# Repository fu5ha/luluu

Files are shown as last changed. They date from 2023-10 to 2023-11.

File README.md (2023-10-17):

# LuLuu!

A cute and smart arm-warmer sleeve with a 1.3" full color TFT display built into the back of the
hand ^_^

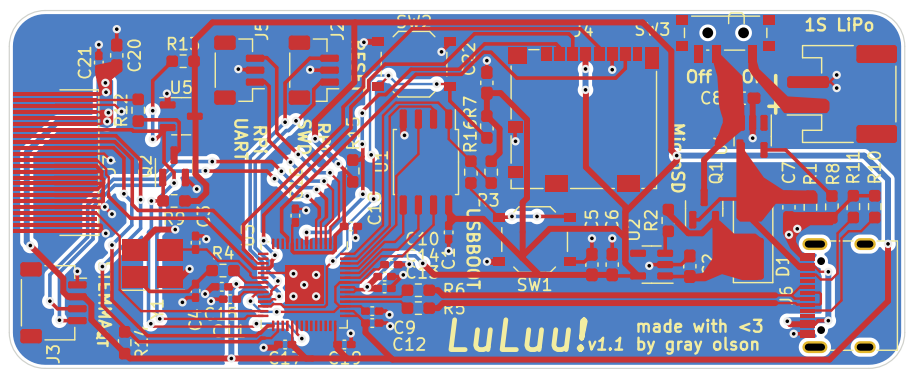
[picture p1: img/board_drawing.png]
PCB drawing

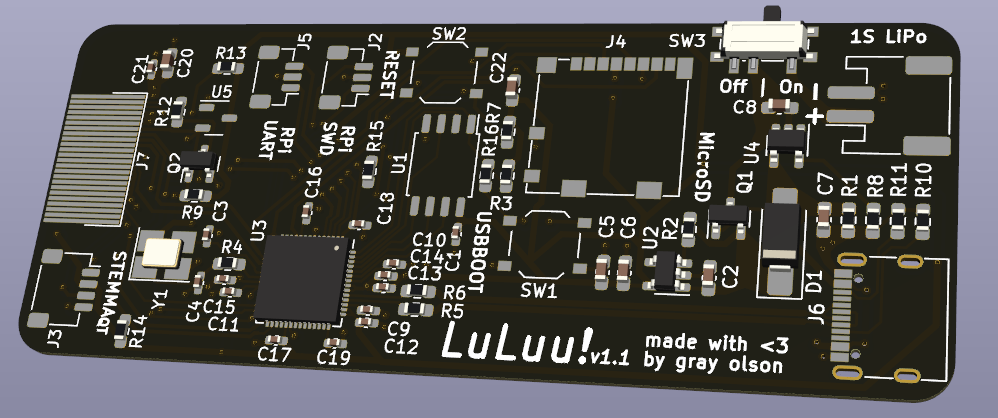
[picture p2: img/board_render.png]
PCB render


## Hardware

Runs on a RaspberryPi RP2040 microcontroller. The small 30x75mm PCB has built-in battery management for a single-cell
LiPo, microSD card storage, and direct connection via SPI to an Adafruit 4520 1.3" TFT (ST7789VW controller). It's
also designed to be expanded via SparkFun Qwiic/Adafruit STEMMA QT compatible (3.3v only) I2C sensor modules. Finallly,
it implements the RaspberryPi 3-wire debug connector spec for ARM SWD serial-wire debugging and RS232-style
UART communication.

The hardware design files all live in the [`hardware/`](hardware/) folder. See the [`README`](hardware/README.md) in
that folder for more.

## Software

The firmware that the LuLuu runs is contained in the [`software/`](software/) folder.
It is written in Rust using some of the amazing Rust embedded tooling.
See the [`README`](software/README.md) in that folder for more.

### Installing

You can either install the firmware using the pre-built binary firmware or you can
build it yourself.

#### Pre-built firmware

You can install a pre-built firmware easily via USB by connecting the LuLuu PCB to
your computer via USB, holding the `USBBOOT` button and then pressing the `RESET`
button. This will put the LuLuu into "USB Bootloader mode," causing a "USB storage" 
device to appear on your computer, into which you can drop the compiled `luluu.uf2`
(TODO: link built firmware).

#### Building yourself

To build yourself, see the [`README`](software/README.md) in the
[`software/`](software/) folder.

## Licenses

Hardware is provided under the CERN Open Hardware License 2.0 Permissive variant.

Software is provided under MIT or Apache-2.0 at your choice.

License texts available in the [`licences/`](licenses/) folder.

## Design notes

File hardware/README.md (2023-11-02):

# Hardware

The main part of this folder is the [KiCad](https://www.kicad.org/) project for the main PCB. Open it with KiCad v7+.
There are production files for PCB production and assembly from JLCPCB in the `production/` folder. There is also a
small 3d printed "front panel" part with exported STL files in the `FrontPanel/` folder.

## Online Schematic and Board View

You can view an explorable online version of the schematic and board layout here:
https://kicanvas.org/?github=https%3A%2F%2Fgithub.com%2Ffu5ha%2Fluluu%2Ftree%2Fmain%2Fhardware

## Order and assembly

The board is specifically designed to be economic and easy to order with JLCPCB's
"economic" PCB assembly service. Boards received from JLC will be mostly-assembled
but still require a few pieces of hand assembly: installing the battery connector,
power switch, display connection cable, (optionally) debug connectors, and
(optionally) STEMMAqt connector.

TODO: document BOM, assembly process, etc more

## Front Panel

The front panel part was designed in OnShape. The exported files (printed at JLCPCB in my case but could be printed on
any 3d printer really) can be found in the `FrontPanel/` folder. The original OnShape document can be viewed and
remixed here:

https://cad.onshape.com/documents/f8b0c88e73a74b1a499f2bc3/w/d7cf90c156d1df4edfe95550/e/d6b63c8b8542f003553d2207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

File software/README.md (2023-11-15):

# LuLuu! software

LuLuu's software stack is based on the Rust embedded and rp2040 tooling.

The firmware is split into a couple of crates housed in the root Cargo workspace.
We provide our own "board support crate", [`luluu-bsp`](./luluu-bsp), and leverage
that crate in the actual firmware, contained in the [`luluu`](./luluu) folder.

There is also `luluu-enc`, a custom animated image encoding format for the LuLuu, and
`luluu-cli` whose main purpose is to convert `.GIF`s into `.LU`s which can be read and
displayed by the devide.

Using Rust embedded crates:

- `rp2040-hal`
- `embedded-hal`
- `embedded-sdmmc-rs`
- `display-interface`
- `mipidsi`

## Building and flashing the `luluu` firmware

In order to build the firmware yourself, you'll need to:

1. Initialize and update git submodules

We vendor some of our dependencies under the `vendored` directory. Because of this, you'll need
to init and update git submodules in order to build.

```
git submodule update --init
```

2. Install the latest Rust and the `thumbv6m-none-eabi` target. First,
[install `rustup`](https://rustup.rs/). Then,

```
rustup self update
rustup update stable
rustup target add thumbv6m-none-eabi
```

3. Install [`flip-link`](https://github.com/knurling-rs/flip-link)

```
cargo install flip-link
```

Then you can build the firmware by changing into the `luluu` directory and using
`cargo build --release`. In order to install the built firmware on the LuLuu unit,
you have two options.

### Installing with `elf2uf2-rs`

This does not require an ARM 2-wire SWD capable probe, but is a bit cumbersome for
live development and does not provide debugging capabilities.

1. Install [`elf2uf2-rs`](https://github.com/JoNil/elf2uf2-rs)

```
cargo install elf2uf2-rs
```

2. Change directory to the `luluu` directory within this `software` directory

```
cd luluu
```

3. Put the LuLuu into "USB Bootloader mode". Do this by connecting the unit
via USB to your computer, then hold `USBBOOT` button and press the `RESET` button.
If on Linux, you may need to manually mount the device like you would a USB storage
device.

4. Run `cargo run --release` to build and install the firmware to the device

```
cargo run --release
```

### Installing with `cargo embed`

This requires a [`probe-rs`-compatible probe](https://probe.rs/docs/getting-started/probe-setup/).
For example, a [RaspberryPi Debug Probe](https://www.raspberrypi.com/products/debug-probe/)
which LuLuu was designed to work with.

1. Install [`probe-rs`](https://crates.io/crates/probe-rs)

You may need to install prerequisites as well;
[see this page](https://probe.rs/docs/getting-started/installation/). If you're
on Linux, you may also need to change your `udev` rules, as specified
[here](https://probe.rs/docs/getting-started/probe-setup/).

```
cargo install probe-rs --features cli
```

2. Connect the LuLuu unit to power (i.e. plug it into a USB port; the port will
not be used for data in this configuration) as well as through its SWD port to
your probe.

3. Change directory to the `luluu` directory within this `software` directory

```
cd luluu
```

4. Run `cargo embed` to execute the `probe-rs` session

This compile, flash the device through the probe, and start running a debug session
according to `Embed.toml`.

To flash the fully release, no logging version:

```
cargo embed --release
```

To flash a release build but with logging enabled and start a defmt log console

```
cargo embed probe --release --features probe
```

This selects the "probe" profile from `Embed.toml` and enables the `probe` cargo feature
on the `luluu` crate, which enables its logging functionalities.

You can enable more or less verbose logging by modifying the `DEFMT_LOG` env variable
and `luluu/Cargo.toml`, for example uncomment the `embedded-sdmmc-rs/defmt-log` line to
enable logging from the library used to communicate with the SD card:

```
DEFMT_LOG=embedded_sdmmc=trace,luluu=debug cargo embed probe --release --features probe
```

## Converting GIFs with `luluu-cli`

You can convert animated gifs that are 60x60 or 120x120px in size and <= 15 frames per second
into `.LU` files that are used by the device by using the `luluu-cli` crate.

1. Change into the `luluu-cli` directory

```
cd luluu-cli
```

2. Run the tool, specifying the convert subcommand and a path to the file.

```
cargo run --release convert [FILE_PATH]
```

The tool will write the output file with the same name directly next to the original GIF provided.

You can get more help with

```
cargo run --release -- -h
```

or

```
cargo run --release -- convert -h
```

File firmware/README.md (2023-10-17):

# LuLuu! software

LuLuu's software stack is based on the Rust embedded and rp2040 tooling. 

TODO. Using Rust embedded crates:

- `embedded-hal` (`rp2040-hal`)
- `embedded-sdmmc`
- `embedded-graphics`
- `tinybmp`/`tinygif`
- `display-interface`
- `mipidsi`

## Building and installing

In order to build the firmware yourself, you'll need to:

1. Install the latest Rust and the `thumbv6m-none-eabi` target. First,
[install `rustup`](https://rustup.rs/). Then,

```
rustup self update
rustup update stable
rustup target add thumbv6m-none-eabi
```

2. Install [`flip-link`](https://github.com/knurling-rs/flip-link)

```
cargo install flip-link
```

Then you can build the firmware with `cargo build --release`. In order to install
the built firmware on the LuLuu unit, you have two options.

### Installing with `elf2uf2-rs`

This does not require an ARM 2-wire SWD capable probe, but is a bit cumbersome for
live development and does not provide debugging capabilities.

1. Install [`elf2uf2-rs`](https://github.com/JoNil/elf2uf2-rs)

```
cargo install elf2uf2-rs	
```

2. Change `.cargo/config` to use `elf2uf2-rs` as runner

Find `[target.thumbv6m-none-eabi]` and change it like so:

```toml
[target.thumbv6m-none-eabi]
runner = "elf2uf2-rs -d"
```

3. Put the LuLuu into "USB Bootloader mode". Do this by connecting the unit
via USB to your computer, then hold `USBBOOT` button and press the `RESET` button.
If on Linux, you may need to manually mount the device like you would a USB storage
device.

4. Run `cargo run --release` to build and install the firmware to the device

```
cargo run --release	
```

### Installing with `probe-rs`

This requires a [`probe-rs`-compatible probe](https://probe.rs/docs/getting-started/probe-setup/).
For example, a [RaspberryPi Debug Probe](https://www.raspberrypi.com/products/debug-probe/)
which LuLuu was designed to work with.

1. Install [`probe-rs`](https://crates.io/crates/probe-rs)

You may need to install prerequisites as well;
[see this page](https://probe.rs/docs/getting-started/installation/). If you're
on Linux, you may also need to change your `udev` rules, as specified
[here](https://probe.rs/docs/getting-started/probe-setup/).

```
cargo install probe-rs --features cli
```

2. Connect the LuLuu unit to power (i.e. plug it into a USB port; the port will
not be used for data in this configuration) as well as through its SWD port to
your probe.

3. Customize `Embed.toml` if desired.

See [the `probe-rs` repo for reference](https://github.com/probe-rs/probe-rs/blob/c0610e98008cbb34d0dc056fcddff0f2d4f50ad5/probe-rs/src/bin/probe-rs/cmd/cargo_embed/config/default.toml).

4. Run `cargo run --release` to execute the `probe-rs` session

This compile, flash the device through the probe, and start running a debug session
according to the `Embed.toml`.

```
cargo run --release
```

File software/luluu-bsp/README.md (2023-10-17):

# `luluu-bsp` - Board Support for the LuLuu!

You should include this crate if you are writing code that you want to run on
the LuLuu! board.

This crate includes the [rp2040-hal], but also configures each pin of the
RP2040 chip according to how it is connected up on the LuLuu.

The layout of the LuLuu! is intentionally very similar to the
[Adafruit Feather RP2040].

[Adafruit Feather RP2040]: https://www.adafruit.com/product/4884
[rp2040-hal]: https://github.com/rp-rs/rp-hal/tree/main/rp2040-hal

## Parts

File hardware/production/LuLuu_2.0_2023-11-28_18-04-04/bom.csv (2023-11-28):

Designator | Footprint | Quantity | Value | LCSC Part #
C1, C10, C11, C13, C14, C15, C16, C17, C18, C19, C23 | 0402 | 11 | 100nf | C1525
C12, C9 | 0402 | 2 | 1uf | C52923
C2, C20, C22, C5, C6, C7, C8 | 0603 | 7 | 10uf | C96446
C3, C4 | 0402 | 2 | 30pf | C1570
D1 | D_SMA_Handsoldering | 1 | SS34 | C8678
D2 | 0805 | 1 | CHRG | C2296
J4 | microSD_HC_Molex_104031-0811 | 1 | Micro_SD_Card | C585350
J6 | USB_C_Receptacle_G-Switch_GT-USB-7010ASV | 1 | USB_C_Receptacle_USB2.0 | C2988369
J7 | FPC_24_JUSHUO_AFC04-S24XCA-00 | 1 | DISP_LCD_ST7789 | C883644
Q1 | SOT-23 | 1 | AO3401A | C15127
Q2 | SOT-23 | 1 | BSS138 | C7420339
R1, R13, R14, R15, R17, R2, R3, R7 | 0603 | 8 | 10k | C25804
R10, R11, R18, R19, R8 | 0603 | 5 | 5.1k | C23186
R12 | 0603 | 1 | 10 | C22859
R16 | 0603 | 1 | 1k | C25804
R20, R9 | 0603 | 2 | 10k | C23186
R4 | 0603 | 1 | 1k | C21190
R5, R6 | 0603 | 2 | 27 | C25190
SW1 | SW_Push_1P1T_XKB_TS-1187A | 1 | SW_B | C318884
SW2 | SW_Push_1P1T_XKB_TS-1187A | 1 | SW_A | C318884
U1 | SOIC-8_5.23x5.23mm_P1.27mm | 1 | W25Q128JVSS | C97521
U2 | SOT-23-5 | 1 | RT9080-33GJ5 | C841192
U3 | QFN-56-1EP_7x7mm_P0.4mm_EP3.2x3.2mm | 1 | RP2040 | C2040
U4 | SOT-23-5 | 1 | TP4054-42 | C32574
U5 | LGA-16_3x3mm_P0.5mm_LayoutBorder3x5y | 1 | LIS3DH | C15134
Y1 | Crystal_SMD_3225-4Pin_3.2x2.5mm_HandSoldering | 1 | X322512MSB4SI | C9002

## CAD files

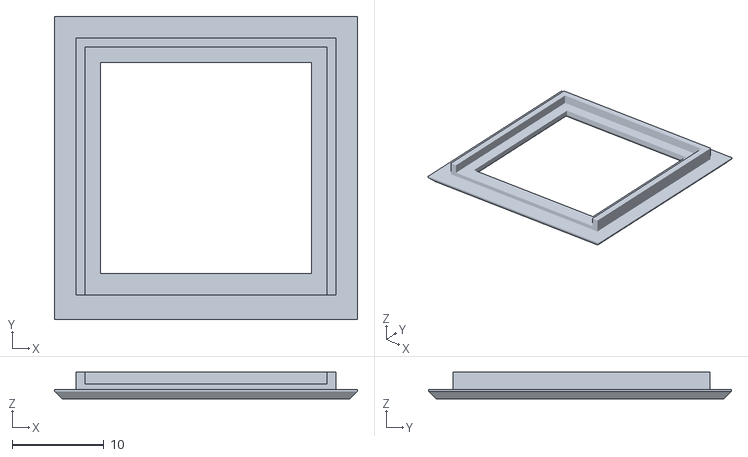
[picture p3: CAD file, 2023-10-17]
hardware/FrontPanel/LuLuuFrontPanelThin.stl
33.0 x 33.0 x 2.90

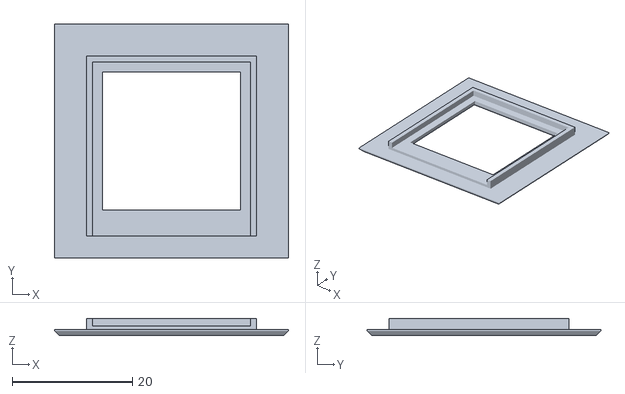
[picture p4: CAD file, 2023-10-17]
hardware/FrontPanel/LuLuuFrontPanelWide.stl
39.0 x 39.0 x 2.90

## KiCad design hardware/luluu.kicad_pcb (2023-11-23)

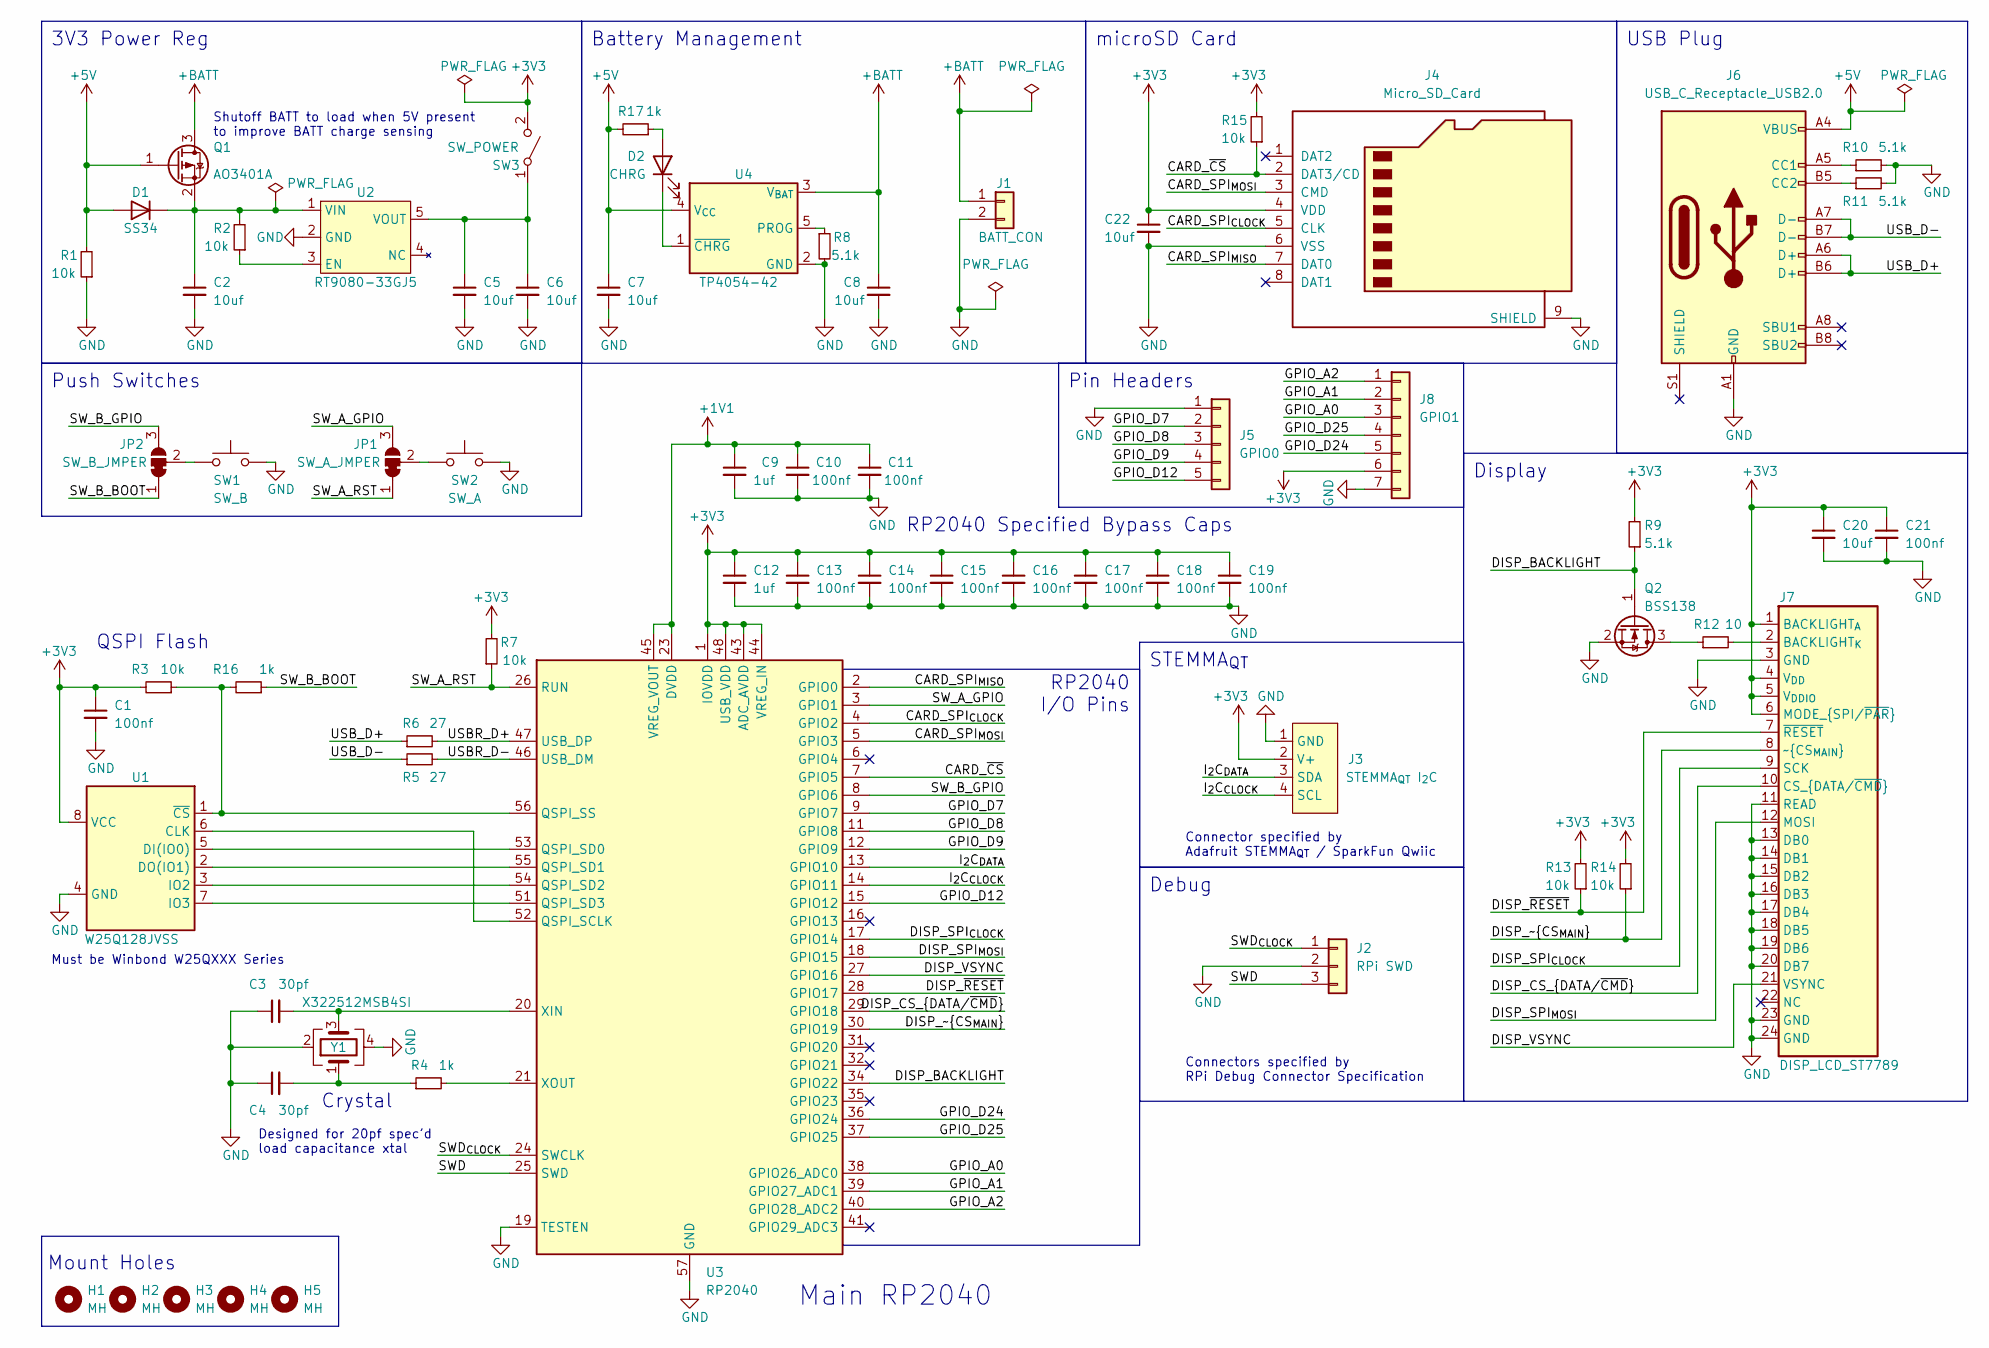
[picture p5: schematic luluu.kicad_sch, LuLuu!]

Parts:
C1, C10, C11, C13, C14, C15, C16, C17, C18, C19, C21: 100nf; C_0402_1005Metric_Pad0.74x0.62mm_HandSolder; LCSC C1525
C2, C5, C6, C7, C8, C20, C22: 10uf; C_0603_1608Metric_Pad1.08x0.95mm_HandSolder; LCSC C96446
C3, C4: 30pf; C_0402_1005Metric_Pad0.74x0.62mm_HandSolder; LCSC C1570
C9, C12: 1uf; C_0402_1005Metric_Pad0.74x0.62mm_HandSolder; LCSC C52923
D1: SS34; D_SMA_Handsoldering; LCSC C8678
D2: CHRG; LED_0805_2012Metric_Pad1.15x1.40mm_HandSolder; LCSC C2296
H1, H2, H3, H4, H5: MH; MountingHole_1.1mm_M1
J1: BATT_CON; JST_PH_S2B-PH-SM4-TB_1x02-1MP_P2.00mm_Horizontal; DigiKey 455-S2B-PH-SM4-TBCT-ND
J2: RPi SWD; JST_SH_BM03B-SRSS-TB_1x03-1MP_P1.00mm_Vertical; DigiKey 455-BM03B-SRSS-TBCT-ND
J3: STEMMA_{QT} I_{2}C; JST_SH_SM04B-SRSS-TB_1x04-1MP_P1.00mm_Horizontal; DigiKey 455-SM04B-SRSS-TBCT-ND
J4: Micro_SD_Card; microSD_HC_Molex_104031-0811; LCSC C585350
J5: GPIO0; PinHeader_1x05_P2.54mm_Vertical
J6: USB_C_Receptacle_USB2.0; USB_C_Receptacle_G-Switch_GT-USB-7010ASV; LCSC C2988369
J7: DISP_LCD_ST7789; FPC_24_SOLDER; DigiKey WM11305-ND
J8: GPIO1; PinHeader_1x07_P2.54mm_Vertical
JP1: SW_A_JMPER; SolderJumper-3_P1.3mm_Bridged12_RoundedPad1.0x1.5mm
JP2: SW_B_JMPER; SolderJumper-3_P1.3mm_Bridged12_RoundedPad1.0x1.5mm
Q1: AO3401A; SOT-23; LCSC C15127
Q2: BSS138; SOT-23; LCSC C7420339
R1, R2, R3, R7, R13, R14, R15: 10k; R_0603_1608Metric_Pad0.98x0.95mm_HandSolder; LCSC C25804
R4: 1k; R_0603_1608Metric_Pad0.98x0.95mm_HandSolder; LCSC C21190
R5, R6: 27; R_0603_1608Metric_Pad0.98x0.95mm_HandSolder; LCSC C25190
R8, R9, R10, R11: 5.1k; R_0603_1608Metric_Pad0.98x0.95mm_HandSolder; LCSC C23186
R12: 10; R_0603_1608Metric_Pad0.98x0.95mm_HandSolder; LCSC C22859
R16, R17: 1k; R_0603_1608Metric_Pad0.98x0.95mm_HandSolder; LCSC C25804
SW1: SW_B; SW_Push_1P1T_XKB_TS-1187A; LCSC C318884
SW2: SW_A; SW_Push_1P1T_XKB_TS-1187A; LCSC C318884
SW3: SW_POWER; SW_SPDT_PCM12; DigiKey 401-2016-1-ND
U1: W25Q128JVSS; SOIC-8_5.23x5.23mm_P1.27mm; LCSC C97521
U2: RT9080-33GJ5; SOT-23-5; LCSC C841192
U3: RP2040; QFN-56-1EP_7x7mm_P0.4mm_EP3.2x3.2mm; LCSC C2040
U4: TP4054-42; SOT-23-5; LCSC C32574
Y1: X322512MSB4SI; Crystal_SMD_3225-4Pin_3.2x2.5mm_HandSoldering; LCSC C9002

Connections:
+1V1: C9.1, C10.1, C11.1, U3.23 (DVDD), U3.45 (VREG_VOUT), U3.50 (DVDD)
+3V3: C1.1, C12.1, C13.1, C14.1, C15.1, C16.1, C17.1, C18.1, C19.1, C20.1, C21.1, C22.1, J3.2 (V+), J4.4 (VDD), J7.1 (BACKLIGHT_{A}), J7.4 (V_{DD}), J7.5 (V_{DDIO}), J7.6 (MODE_{SPI/~PAR}), J8.6, R3.2, R7.2, R9.2, R13.2, R14.2, R15.2, SW3.2 (B), U1.8 (VCC), U3.1 (IOVDD), U3.10 (IOVDD), U3.22 (IOVDD), U3.33 (IOVDD), U3.42 (IOVDD), U3.43 (ADC_AVDD), U3.44 (VREG_IN), U3.48 (USB_VDD), U3.49 (IOVDD)
+5V: C7.1, D1.2 (A), J6.A4 (VBUS), J6.A9 (VBUS), J6.B4 (VBUS), J6.B9 (VBUS), Q1.1 (G), R1.2, R17.2, U4.4 (V_{CC})
+BATT: C8.1, J1.1, Q1.3 (D), U4.3 (V_{BAT})
/CARD_SPI_{CLOCK}: J4.5 (CLK), U3.4 (GPIO2)
/CARD_SPI_{MISO}: J4.7 (DAT0), U3.2 (GPIO0)
/CARD_SPI_{MOSI}: J4.3 (CMD), U3.5 (GPIO3)
/CARD_~CS: J4.2 (DAT3/CD), R15.1, U3.7 (GPIO5)
/DISP_BACKLIGHT: Q2.1 (G), R9.1, U3.34 (GPIO22)
/DISP_CS_{DATA/~CMD}: J7.10 (CS_{DATA/~CMD}), U3.29 (GPIO18)
/DISP_SPI_{CLOCK}: J7.9 (SCK), U3.17 (GPIO14)
/DISP_SPI_{MOSI}: J7.12 (MOSI), U3.18 (GPIO15)
/DISP_VSYNC: J7.21 (VSYNC), U3.27 (GPIO16)
/DISP_~CS_{MAIN}: J7.8 (~CS_{MAIN}), R14.1, U3.30 (GPIO19)
/DISP_~RESET: J7.7 (~RESET), R13.1, U3.28 (GPIO17)
/GPIO_A0: J8.3, U3.38 (GPIO26_ADC0)
/GPIO_A1: J8.2, U3.39 (GPIO27_ADC1)
/GPIO_A2: J8.1, U3.40 (GPIO28_ADC2)
/GPIO_D7: J5.2, U3.9 (GPIO7)
/GPIO_D8: J5.3, U3.11 (GPIO8)
/GPIO_D9: J5.4, U3.12 (GPIO9)
/GPIO_D12: J5.5, U3.15 (GPIO12)
/GPIO_D24: J8.5, U3.36 (GPIO24)
/GPIO_D25: J8.4, U3.37 (GPIO25)
/I_{2}C_{CLOCK}: J3.4 (SCL), U3.14 (GPIO11)
/I_{2}C_{DATA}: J3.3 (SDA), U3.13 (GPIO10)
/SWD: J2.3, U3.25 (SWD)
/SWD_{CLOCK}: J2.1, U3.24 (SWCLK)
/SW_A_GPIO: JP1.3 (B), U3.3 (GPIO1)
/SW_A_RST: JP1.1 (A), R7.1, U3.26 (RUN)
/SW_B_BOOT: JP2.1 (A), R16.1
/SW_B_GPIO: JP2.3 (B), U3.8 (GPIO6)
/USBR_D+: R6.2, U3.47 (USB_DP)
/USBR_D-: R5.2, U3.46 (USB_DM)
/USB_D+: J6.A6 (D+), J6.B6 (D+), R6.1
/USB_D-: J6.A7 (D-), J6.B7 (D-), R5.1
GND: C1.2, C2.2, C3.1, C4.1, C5.2, C6.2, C7.2, C8.2, C9.2, C10.2, C11.2, C12.2, C13.2, C14.2, C15.2, C16.2, C17.2, C18.2, C19.2, C20.2, C21.2, C22.2, J1.2, J2.2, J3.1 (GND), J4.6 (VSS), J4.9 (SHIELD), J5.1, J6.A1 (GND), J6.A12 (GND), J6.B1 (GND), J6.B12 (GND), J7.3 (GND), J7.11 (READ), J7.13 (DB0), J7.14 (DB1), J7.15 (DB2), J7.16 (DB3), J7.17 (DB4), J7.18 (DB5), J7.19 (DB6), J7.20 (DB7), J7.23 (GND), J7.24 (GND), J8.7, Q2.2 (S), R1.1, R8.2, R10.2, R11.2, SW1.2, SW2.1, U1.4 (GND), U2.2 (GND), U3.19 (TESTEN), U3.57 (GND), U4.2 (GND), Y1.2, Y1.4
unnamed: C4.2, R4.1, Y1.1
unnamed: C2.1, D1.1 (K), Q1.2 (S), R2.2, U2.1 (VIN)
unnamed: D2.2 (A), R17.1
unnamed: D2.1 (K), U4.1 (~CHRG)
unnamed: J6.A5 (CC1), R10.1
unnamed: J6.B5 (CC2), R11.1
unnamed: J7.2 (BACKLIGHT_{K}), R12.2
unnamed: JP1.2 (C), SW2.2
unnamed: JP2.2 (C), SW1.1
unnamed: Q2.3 (D), R12.1
unnamed: C5.1, C6.1, SW3.1 (A), U2.5 (VOUT)
unnamed: U1.6 (CLK), U3.52 (QSPI_SCLK)
unnamed: U1.5 (DI(IO0)), U3.53 (QSPI_SD0)
unnamed: U1.2 (DO(IO1)), U3.55 (QSPI_SD1)
unnamed: U1.3 (IO2), U3.54 (QSPI_SD2)
unnamed: U1.7 (IO3), U3.51 (QSPI_SD3)
unnamed: R3.1, R16.2, U1.1 (~CS), U3.56 (QSPI_SS)
unnamed: R2.1, U2.3 (EN)
unnamed: C3.2, U3.20 (XIN), Y1.3
unnamed: R4.2, U3.21 (XOUT)
unnamed: R8.1, U4.5 (PROG)

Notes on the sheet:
RP2040 Specified Bypass Caps
QSPI Flash
Pin Headers
Main RP2040
Must be Winbond W25QXXX Series
Push Switches
Mount Holes
Display
RP2040 I/O Pins
USB Plug
Connector specified by Adafruit STEMMA_{QT} / SparkFun Qwiic
Crystal
microSD Card
STEMMA_{QT}
Battery Management
3V3 Power Reg
Connectors specified by RPi Debug Connector Specification
Debug
Designed for 20pf spec'd load capacitance xtal
Shutoff BATT to load when 5V present to improve BATT charge sensing

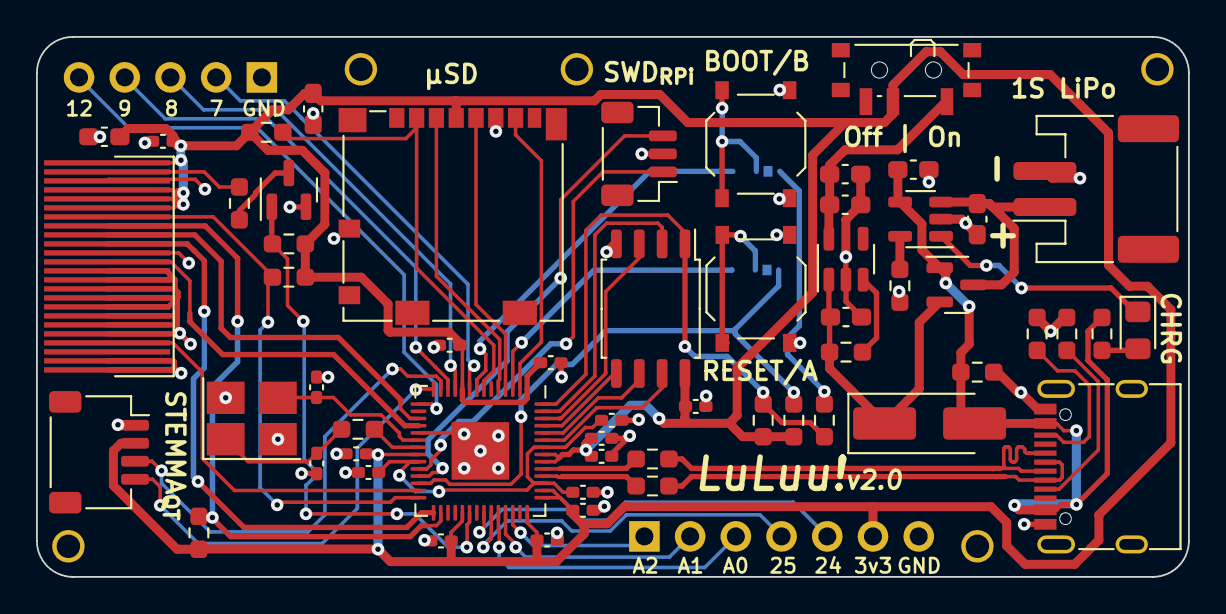
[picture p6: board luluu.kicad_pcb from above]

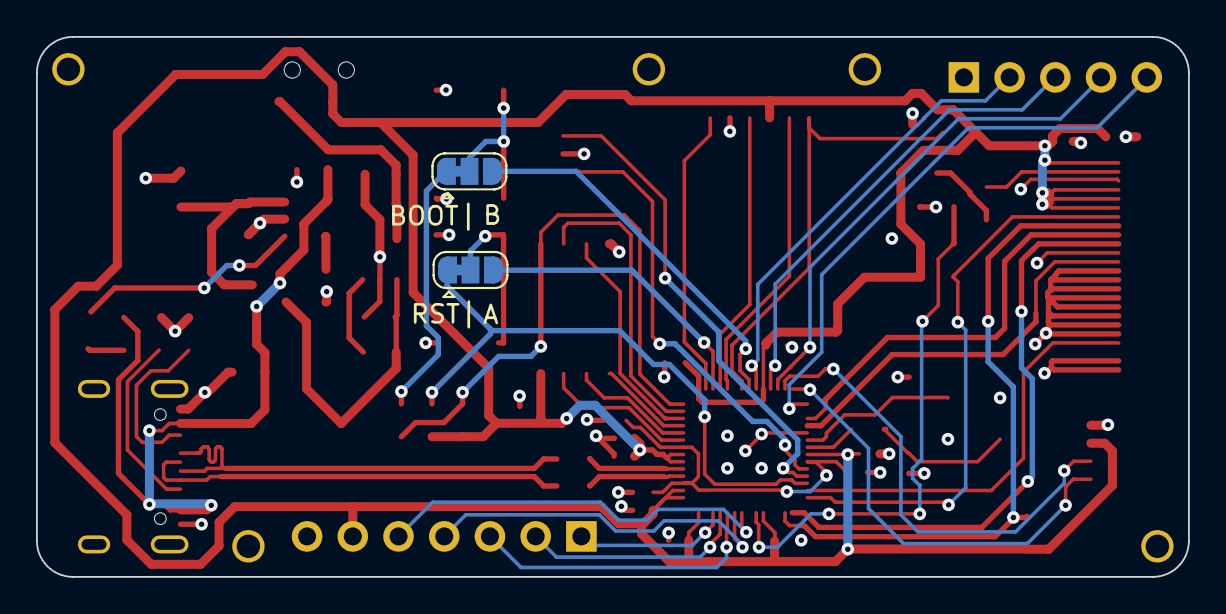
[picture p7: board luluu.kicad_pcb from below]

Board: 4 copper layers, 64.0 x 30.0 mm, 66 parts (2 on the bottom side), 58 nets.

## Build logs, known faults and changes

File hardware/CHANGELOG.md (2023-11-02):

# CHANGELOG

# Rev 1.1

- Fix USB D+/D- mismatch
- Add 1k resistor in series with USBBOOT pulldown switch as recommended by RP2040 design layout guide.

# Rev 1

Initial design

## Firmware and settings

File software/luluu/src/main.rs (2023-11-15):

#![no_std]
#![no_main]

use core::cell::RefCell;
use core::ops::{DerefMut, Deref};
use core::fmt::Write;

use bsp::hal::Clock;
use bsp::hal::rosc::RingOscillator;
use display_interface_spi::SPIInterface;
use embedded_hal_bus::spi::RefCellDevice;
use embedded_sdmmc::{VolumeIdx, DirEntry};
use embedded_sdmmc::sdcard::{DummyCsPin, AcquireOpts};
use luluu_bsp as bsp;

use bsp::{hal as hal, DispReset, Rgb565BE};
use bsp::{entry, hal::Spi, SpiPinLayout};
use embedded_hal::digital::{OutputPin, InputPin};

#[cfg(feature = "probe")]
use defmt_rtt as _;
#[cfg(feature = "probe")]
use panic_probe as _;
#[cfg(not(feature = "probe"))]
use panic_halt as _;
#[cfg(not(feature = "probe"))]
use core as defmt;

use bsp::hal::{
    clocks::init_clocks_and_plls,
    pac,
    sio::Sio,
    watchdog::Watchdog,
};

use fugit::{RateExtU32, HertzU32};

use crate::read_file::{read_60px_frame_into_main_fb, read_240px_frame_into_main_fb};
use crate::read_file::read_120px_frame_into_main_fb;

mod read_file;

/// The `.sram4` section spans SRAM bank 4, which is 4KiB
pub const FILE_BUFFER_SIZE: usize = 1024 * 4;

bsp::singleton! {
    FileReadBuffer {
        #[link_section = ".sram4"]
        #[used]
        static mut FILE_BUFFER: [u8; FILE_BUFFER_SIZE] = [0u8; FILE_BUFFER_SIZE];
    }
}

bsp::singleton! {
    MainFramebuffer {
        static mut MAIN_FRAMEBUFFER: bsp::Framebuffer<Rgb565BE> = bsp::Framebuffer::const_new(Rgb565BE::ZERO);
    }
}

const SD_BAUDRATE: HertzU32 = HertzU32::kHz(31_250);
const DISP_BAUDRATE: HertzU32 = HertzU32::kHz(62_500);


#[entry]
fn main() -> ! {
    let mut peripherals = pac::Peripherals::take().unwrap();
    let mut watchdog = Watchdog::new(peripherals.WATCHDOG);

    let clocks = init_clocks_and_plls(
        bsp::XOSC_CRYSTAL_FREQ,
        bsp::XOSC_STABLE_DELAY_MILLIS,
        peripherals.XOSC,
        peripherals.CLOCKS,
        peripherals.PLL_SYS,
        peripherals.PLL_USB,
        &mut peripherals.RESETS,
        &mut watchdog,
    )
    .ok()
    .unwrap();

    let mut fb = unsafe { MainFramebuffer::acquire() };
    let mut file_read_buffer = unsafe { FileReadBuffer::acquire() };

    let core = pac::CorePeripherals::take().unwrap();

    let mut delay = cortex_m::delay::Delay::new(core.SYST, 125_000_000);

    let mut timer = hal::Timer::new(peripherals.TIMER, &mut peripherals.RESETS, &clocks);

    let sio = Sio::new(peripherals.SIO);

    let mut pins = bsp::Pins::new(
        peripherals.IO_BANK0,
        peripherals.PADS_BANK0,
        sio.gpio_bank0,
        &mut peripherals.RESETS,
    );

    let mut disp_backlight = pins.disp_backlight;
    disp_backlight.set_low().unwrap();

    pins.spi_mosi.set_slew_rate(hal::gpio::OutputSlewRate::Fast);
    pins.spi_miso.set_slew_rate(hal::gpio::OutputSlewRate::Fast);
    pins.spi_clock.set_slew_rate(hal::gpio::OutputSlewRate::Fast);

    let spi_pin_layout: SpiPinLayout = (pins.spi_mosi, pins.spi_miso, pins.spi_clock);
    let spi = Spi::new(peripherals.SPI1, spi_pin_layout);

    // start at low baud rate for initializing card
    let init = spi.init(&mut peripherals.RESETS, clocks.peripheral_clock.freq(), 200.kHz(), embedded_hal::spi::MODE_0);
    let spi = init;

    let shared_spi = RefCell::new(spi);

    let sdcard_spi: RefCellDevice<'_, Spi<hal::spi::Enabled, pac::SPI1, (hal::gpio::Pin<hal::gpio::bank0::Gpio15, hal::gpio::FunctionSpi, hal::gpio::PullNone>, hal::gpio::Pin<hal::gpio::bank0::Gpio8, hal::gpio::FunctionSpi, hal::gpio::PullDown>, hal::gpio::Pin<hal::gpio::bank0::Gpio14, hal::gpio::FunctionSpi, hal::gpio::PullNone>), 8>, DummyCsPin, hal::Timer> = RefCellDevice::new(&shared_spi, DummyCsPin, timer.clone());

    pins.card_cs.set_slew_rate(hal::gpio::OutputSlewRate::Fast);
    let card_cs = pins.card_cs;

    let sdcard = embedded_sdmmc::SdCard::new_with_options(
        sdcard_spi,
        card_cs,
        timer.clone(),
        AcquireOpts {
            use_crc: true,
            ..Default::default()
        }
    );

    let mut volume_mgr = embedded_sdmmc::VolumeManager::<_, _, 1, 1, 1>::new_with_limits(sdcard, bsp::DummyTimesource, 0);
    let mut volume0 = volume_mgr.open_volume(VolumeIdx(0)).unwrap();
    let mut root_dir = volume0.open_root_dir().unwrap();
    let mut dir_entries: heapless::Vec<DirEntry, 16> = heapless::Vec::new();
    root_dir.iterate_dir(|dir_entry| {
        if dir_entries.is_full() {
            return;
        }
        if dir_entry.attributes.is_hidden() || dir_entry.attributes.is_system() {
            return;
        }
        if dir_entry.name.extension() == b"LU" {
            dir_entries.push(dir_entry.clone()).unwrap();
        }
    }).unwrap();

    defmt::assert!(dir_entries.len() > 0);

    let mut rosc = RingOscillator::new(peripherals.ROSC).initialize();
    let file_idx = (bsp::gen_rand_u32(&mut rosc) % dir_entries.len() as u32) as usize;

    let dir_entry = &dir_entries[file_idx];

    let mut img_file = root_dir.open_file_in_dir(&dir_entry.name, embedded_sdmmc::Mode::ReadOnly).unwrap();

    let mut dir_name: heapless::String<16> = heapless::String::new();
    write!(&mut dir_name, "{}", &dir_entry.name).unwrap();
    #[cfg(feature = "probe")]
    defmt::info!("found {}, size: {}", dir_name, dir_entry.size);

    let _baud = shared_spi.borrow_mut().set_baudrate(125.MHz(), SD_BAUDRATE);
    #[cfg(feature = "probe")]
    defmt::info!("set spi baud: {}", _baud);

    let read = img_file.read(&mut file_read_buffer[0..bsp::luluu_enc::HEADER_SIZE]).unwrap();

    defmt::assert_eq!(read, bsp::luluu_enc::HEADER_SIZE);

    let header = bsp::luluu_enc::Header::decode((&file_read_buffer[..bsp::luluu_enc::HEADER_SIZE]).try_into().unwrap()).unwrap();

    defmt::assert_eq!(header.encoding, bsp::luluu_enc::Encoding::RGB565BE);

    match header.size.0 {
        60 => read_60px_frame_into_main_fb(&mut img_file, &mut *file_read_buffer, &mut *fb),
        120 => read_120px_frame_into_main_fb(&mut img_file, &mut *file_read_buffer, &mut *fb),
        240 => read_240px_frame_into_main_fb(&mut img_file, &mut *file_read_buffer, &mut *fb),
        _ => defmt::unreachable!(),
    }

    #[cfg(feature = "probe")]
    defmt::info!("frame rate: {}", header.frame_rate);

    let display_frame_rate = match header.size.0 {
        60 | 120 => {
            match header.frame_rate.0 {
                1..=2 => mipidsi::FrameRate::Hz40,
                3 => mipidsi::FrameRate::Hz42,
                4 => mipidsi::FrameRate::Hz40,
                5 => mipidsi::FrameRate::Hz40,
                6 => mipidsi::FrameRate::Hz60,
                8 => mipidsi::FrameRate::Hz72,
                10 => mipidsi::FrameRate::Hz90,
                12 => mipidsi::FrameRate::Hz72,
                15 => mipidsi::FrameRate::Hz90,
                20 => mipidsi::FrameRate::Hz99,
                24 => mipidsi::FrameRate::Hz72,
                _ => defmt::unreachable!(),
            }
        }
        240 => {
            match header.frame_rate.0 {
                1..=2 => mipidsi::FrameRate::Hz40,
                3 => mipidsi::FrameRate::Hz60,
                4 => mipidsi::FrameRate::Hz90,
                _ => defmt::unreachable!(),
            }
        }
        _ => defmt::unreachable!()
    };

    let mut disp_reset = pins.disp_reset;
    disp_reset.set_slew_rate(hal::gpio::OutputSlewRate::Fast);

    disp_reset.set_low().unwrap();
    delay.delay_us(120);
    disp_reset.set_high().unwrap();
    delay.delay_ms(100);
    // disp_reset.set_low().unwrap();
    // delay.delay_us(10);
    // disp_reset.set_high().unwrap();
    // delay.delay_ms(100);

    shared_spi.borrow_mut().set_baudrate(clocks.peripheral_clock.freq(), 400.kHz());

    pins.disp_cs_main.set_slew_rate(hal::gpio::OutputSlewRate::Fast);
    pins.disp_data_cmd.set_slew_rate(hal::gpio::OutputSlewRate::Fast);
    let disp_cs_main = pins.disp_cs_main;
    let disp_data_cmd = pins.disp_data_cmd;
    let disp_vsync = pins.disp_vsync;

    let display_spi = RefCellDevice::new(&shared_spi, disp_cs_main, timer.clone());
    let display_interface = SPIInterface::new(display_spi, disp_data_cmd);
    let mut options = mipidsi::ModelOptions::with_sizes((240, 240), (240, 240));
    options.set_invert_colors(mipidsi::ColorInversion::Inverted);
    let mut display = mipidsi::Builder::new(display_interface, mipidsi::models::ST7789, options)
        .init(&mut timer, None::<DispReset>)
        .unwrap();
    display.set_tearing_effect(mipidsi::TearingEffect::Vertical).unwrap();
    display.set_frame_rate(display_frame_rate, Default::default()).unwrap();

    let _baud = shared_spi.borrow_mut().set_baudrate(clocks.peripheral_clock.freq(), DISP_BAUDRATE);
    #[cfg(feature = "probe")]
    defmt::info!("set spi baud: {}", _baud);

    let frame_budget_micros: u32 = (1_000_000 / header.frame_rate.0 as u32) - 200;

    let mut frame: u32 = 1; // because we already loaded the first frame.
    loop {
        let start_time = timer.get_counter_low();

        // we want to write starting *during* the time the controller driver is updating the lcd
        // from its internal memory, but *behind* the current place it's reading from its internal
        // memory. in this way we basically get two display-frames to update the display's memory.
        while !disp_vsync.is_high().unwrap() {}
        while disp_vsync.is_high().unwrap() {};
        delay.delay_us(300);

        #[cfg(feature = "probe")]
        let draw_start = timer.get_counter_low();

        display.set_pixels_565be(0, 0, 240, 240, fb.as_bytes()).unwrap();
        if frame == 2 {
            disp_backlight.set_high().unwrap();
        }

        #[cfg(feature = "probe")]
        if frame % 32 == 0 {
            let draw_end = timer.get_counter_low();
            defmt::info!("draw took: {}us", draw_end - draw_start);
        }

        shared_spi.borrow_mut().set_baudrate(clocks.peripheral_clock.freq(), SD_BAUDRATE);

        #[cfg(feature = "probe")]
        let read_start = timer.get_counter_low();

        if frame % header.n_frames.as_u16() as u32 == 0 {
            img_file.seek_from_start(bsp::luluu_enc::HEADER_SIZE as u32).unwrap();
        }

        match header.size.0 {
            60 => read_60px_frame_into_main_fb(&mut img_file, &mut *file_read_buffer, &mut *fb),
            120 => read_120px_frame_into_main_fb(&mut img_file, &mut *file_read_buffer, &mut *fb),
            240 => read_240px_frame_into_main_fb(&mut img_file, &mut *file_read_buffer, &mut *fb),
            _ => defmt::unreachable!(),
        }

        #[cfg(feature = "probe")]
        if (frame + 2) % 32 == 0 {
            let read_end = timer.get_counter_low();
            defmt::info!("modify took: {}us", read_end - read_start);
        }

        let _= shared_spi.borrow_mut().set_baudrate(clocks.peripheral_clock.freq(), DISP_BAUDRATE);

        let current_time = timer.get_counter_low();
        let frame_time = current_time - start_time;
        if let Some(micros_left) = frame_budget_micros.checked_sub(frame_time) {
            #[cfg(feature = "probe")]
            if (frame + 4) % 32 == 0 {
                defmt::info!("waiting for frame: {}us", micros_left);
            }
            delay.delay_us(micros_left);
        } else {
            #[cfg(feature = "probe")]
            if (frame + 4) % 32 == 0 {
                defmt::info!("frame overbudget, had: {} took: {}us", frame_budget_micros, frame_time);
            }
        }

        frame += 1;
    }
}

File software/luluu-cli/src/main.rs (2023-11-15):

use std::{path::PathBuf, fs::File, io::Write};

use clap::{Parser, Subcommand};

use eyre::WrapErr;
use luluu_enc::{Rgb565BE, Rgba8888, Rgb565NE, MagicBytes};

#[derive(Parser)]
#[command(author, version, about, long_about = None)]
struct Cli {
    #[command(subcommand)]
    command: Commands,
}

#[derive(Subcommand)]
enum Commands {
    Convert {
        /// The file to convert
        #[arg(value_name = "FILEPATH")]
        file_path: PathBuf,

        /// Override the output's frame rate. Derived from the GIF if not provided.
        #[arg(short, long, value_name = "FRAMERATE")]
        frame_rate: Option<u8>,
    }
}

fn main() -> Result<(), eyre::Error> {
    pretty_env_logger::init_custom_env("debug,luluu_enc=warn");

    let cli = Cli::parse();
    match &cli.command {
        Commands::Convert { file_path, frame_rate } => {
            let file = File::open(file_path)
                .wrap_err_with(|| format!("Failed to read file to convert from {}", file_path.display()))?;

            let mut decode_opts = gif::DecodeOptions::new();
            decode_opts.set_color_output(gif::ColorOutput::RGBA);

            let mut decoder = decode_opts.read_info(file)
                .wrap_err_with(|| "Found the file, but failed to read it as a GIF.")?;

            let mut delay = None;
            let mut size = None;

            let mut data_buf: Vec<Rgb565BE> = Vec::new();

            let mut frame_number: u16 = 0;
            while let Some(frame) = decoder.read_next_frame()
                .wrap_err_with(|| format!("Failed to read frame {} of provided GIF", frame_number))?
            {
                let frame_size: u8  = match (frame.width, frame.height) {
                    (60, 60) => 60,
                    (120, 120) => 120,
                    (240, 240) => 240,
                    _ => eyre::bail!("Provided GIF is not the right size. It must be either 60x60, 120x120, or 240x240 pixels!"),
                };

                if *size.get_or_insert(frame_size) != frame_size {
                    eyre::bail!("Provided GIF has frames with different sizes. All frames must be 60x60, 120x120, or 240x240 pixels!");
                }

                match &mut delay {
                    delay @ None => *delay = Some(frame.delay),
                    Some(delay) => if *delay != frame.delay {
                        log::warn!("Detected uneven delay between frames. This is unsupported; computing frame rate based on first frame delay.")
                    }
                }

                let frame_data_len = frame_size as usize * frame_size as usize;
                let data_start_idx = data_buf.len();
                data_buf.resize(data_buf.len() + frame_data_len, Rgb565BE::ZERO);

                let src_pixels = Rgba8888::cast_bytes(&*frame.buffer);
                let dst_pixels = &mut data_buf[data_start_idx..(data_start_idx + frame_data_len)];

                for (src_pixel, dst_pixel) in src_pixels.iter().zip(dst_pixels) {
                    let [r, g, b] = src_pixel.rgb();
                    let col_dre_srgb = (r as f32 / 255.0, g as f32 / 255.0, b as f32 / 255.0);
                    // let col_near = decode_srgb(col_dre_srgb);
                    let r_5 = ((col_dre_srgb.0 * (luluu_enc::MAX_5 as f32)) as u8).max(1u8);
                    let g_6 = ((col_dre_srgb.1 * (luluu_enc::MAX_6 as f32)) as u8).max(1u8);
                    let b_5 = ((col_dre_srgb.2 * (luluu_enc::MAX_5 as f32)) as u8).max(1u8);
                    let pixel_565 = Rgb565NE::pack_565(r_5, g_6, b_5);
                    *dst_pixel = pixel_565.to_be();
                }

                frame_number = frame_number
                    .checked_add(1)
                    .ok_or(eyre::eyre!("Too many frames in provided GIF!"))?;
            }

            if frame_number == 0 {
                eyre::bail!("Found a GIF but it had zero frames.");
            }

            let size = luluu_enc::Size(size.unwrap());

            let mut frame_rate = luluu_enc::FrameRate(frame_rate.unwrap_or_else(|| {
                let delay = delay.unwrap().max(1);
                (100 / delay) as u8
            }));

            frame_rate.make_nearest_supported(size).unwrap();

            // supported frame rates: 1, 2, 3, 4, 5, 6, 8, 10, 12, 15

            drop(decoder);

            let header = luluu_enc::Header {
                magic: MagicBytes::CORRECT,
                version: luluu_enc::Version::ZERO,
                encoding: luluu_enc::Encoding::RGB565BE,
                size,
                frame_rate,
                n_frames: luluu_enc::NumFrames::from_u16(frame_number),
            };

            let mut out_file_path = file_path.clone();
            out_file_path.set_extension("LU");

            let mut out_file = File::create(&out_file_path)
                .wrap_err_with(|| format!("Could not create output file: {}", out_file_path.display()))?;

            out_file.write_all(header.as_bytes())
                .wrap_err_with(|| "Failed to write output file.")?;

            out_file.write_all(Rgb565BE::slice_as_bytes(&data_buf))
                .wrap_err_with(|| "Failed to write output file.")?;
        }
    }

    Ok(())
}

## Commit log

2023-10-12 fix usb cc resistor
    [luluu.kicad_sch]
2023-10-12 re-annotate, add display decoupling caps
    [luluu.kicad_sch]
2023-10-12 lots of updates
    [luluu.kicad_sch]
2023-10-13 update footprints and sourcing
    [luluu.kicad_sch]
2023-10-13 remove unnecessary symbol fields
    [luluu.kicad_sch]
2023-10-13 tiny schematic cleanup
    [luluu.kicad_sch]
2023-10-13 design rules
    [luluu.kicad_pcb, luluu.kicad_sch]
2023-10-14 initial routing, various fixes
    [luluu.kicad_pcb, luluu.kicad_sch]
2023-10-14 exclusions, tiny fix
    [luluu.kicad_pcb]
2023-10-14 update pwr switch silkscreen
    [luluu.kicad_pcb, luluu.kicad_sch]
2023-10-16 initial prod
    [bom.csv, designators.csv, luluu.kicad_sch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]
2023-10-16 layout improvements and jlcpcb part positioning offsets
    [bom.csv, designators.csv, luluu.kicad_pcb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]
2023-10-17 add pullups to disp reset, disp csmain, card cs
    [bom.csv, designators.csv, luluu.kicad_pcb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]
2023-10-17 Add front panel part
    [LuLuu_FrontPanel_Thin.stl, LuLuu_FrontPanel_Wide.stl]
2023-10-17 update front panel stls
    [LuLuuFrontPanelThin.stl, LuLuuFrontPanelWide.stl, LuLuu_FrontPanel_Thin.stl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]
2023-10-17 add link to schematic from hardware readme
2023-10-17 change from farnell to digikey for other bom parts
    [luluu.kicad_sch]
2023-11-02 rev1.1 - fix USB data and 1k boot resistor
    [bom.csv, designators.csv, luluu.kicad_pcb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]
2023-11-14 optimize read and blit loop, setup no probe build
2023-11-15 use longer xtal startup delay to fix unstable boot
    [lib.rs, main.rs]
2023-11-15 experimentation with frame rates and sizes
2023-11-17 start on rev2 of pcb
    [luluu.kicad_pcb, luluu.kicad_sch]
2023-11-21 pcb rev 2.0 progress
    [bom.csv, designators.csv, luluu.kicad_pcb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]
2023-11-21 more work on v2.0
    [luluu.kicad_pcb, luluu.kicad_sch]
2023-11-22 optimize usb routing
    [luluu.kicad_pcb]
2023-11-23 more work on v2
    [luluu.kicad_pcb, luluu.kicad_sch]
2023-11-28 2.0 release candidate
    [bom.csv, designators.csv, luluu-rounded.kicad_pcb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]
